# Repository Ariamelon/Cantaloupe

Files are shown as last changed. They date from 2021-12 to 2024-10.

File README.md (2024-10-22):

# Cantaloupe
~60% QMK-compatible split ergonomic keyboard.

## Disclaimer
This keyboard is licensed under CERN-OHL-S-2.0. The layout is based on the [Ergodash](https://github.com/omkbd/ErgoDash) layout with the inner-most keys removed and an improved thumb cluster. The layout was only used as a reference, nothing was copied and the board is a completely new design. In addition, design cues from the [YAEMK](https://karlk90.github.io/yaemk-split-kb/) were used in this design.

## Key Features
* Ergonomic 30-key layout including pinky stagger and arrow keys.
* MX switches with kailh hot-swap sockets.
* 100% reversible design which means only a single board is needed for both sides.
* 0.96" 128x64 SSD1306 OLED support.
* Two rotary encoders supported above the thumb cluster, one on each side.
* Support for the Pimoroni trackball module is also available, replacing one rotary encoder slot.
* On-board ARM STM32F401CCU6 processor.
* USB-C input and split connect ports with full ESD protection.
* SWD breakout header for an alternate means of programming the board.

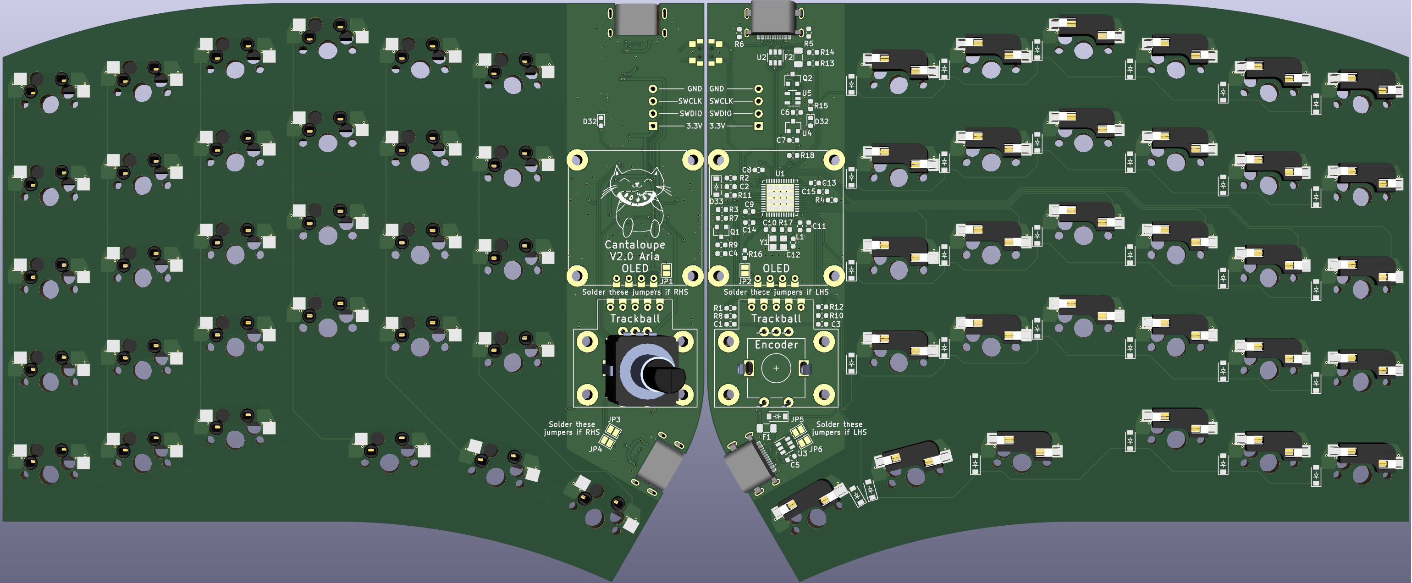
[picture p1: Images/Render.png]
Cantaloupe Front Render

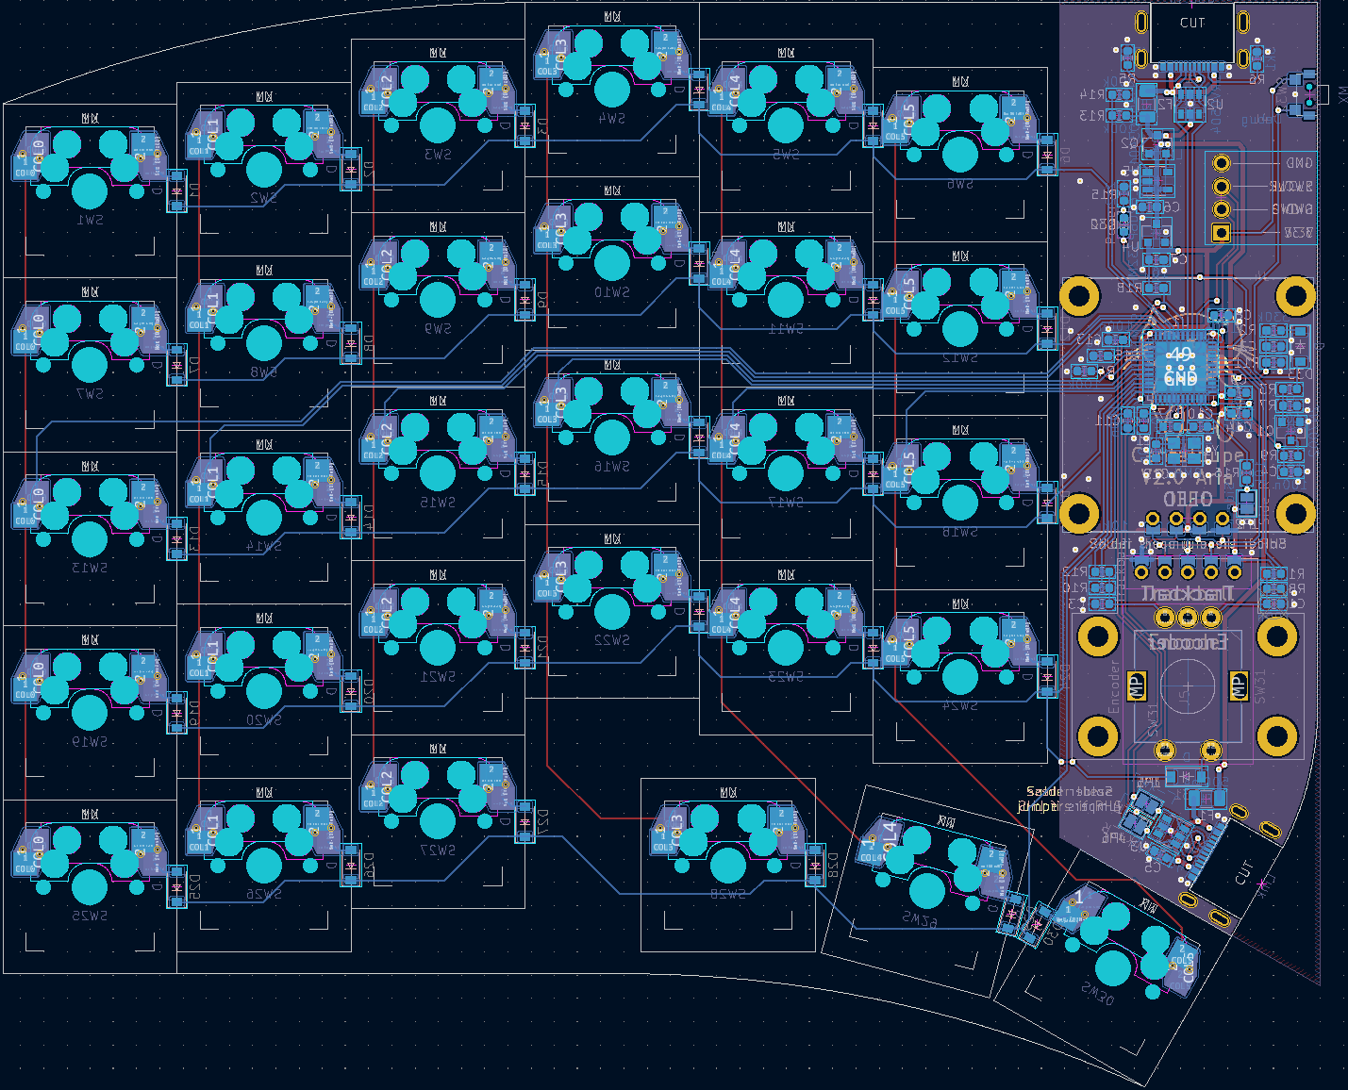
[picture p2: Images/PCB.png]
Cantaloupe PCB

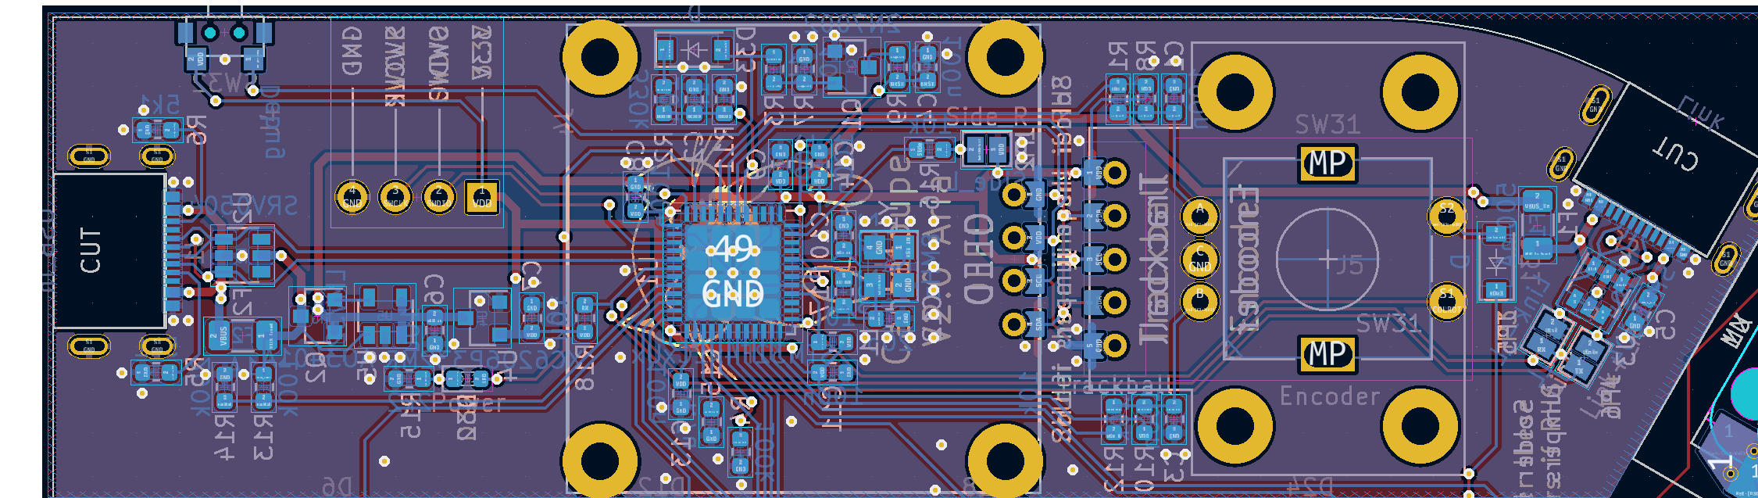
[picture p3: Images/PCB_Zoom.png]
Cantaloupe PCB Zoomed

Cantaloupe Schematic

## Changelog
* 22/10/2024: License updated to CERN-OHL-S-2.0.
* 14/5/2022: Added silkscreen jumper guides. Connected indicator LED to spare GPIO. Updated images.
* 13/5/2022: Finalized firmware. Added custom graphic to OLED display. Updated 3DP case and BOM. Removed CNC case. Fixed error with silkscreen. Added silkscreen jumper guides.
* 15/2/2022: Revised 3DP and CNC case designs.
* 13/2/2022: Added tentative designs for CNC and 3D printed cases. 
* 11/2/2022: Clean up of design. New images. Added gerbers and files for FR4 plates.
* 9/2/2022: Changed pin assignments so B2 isn't used. Added pull-up for RX pin and pull-down for B2 pin so the keyboard can properly load into the bootloader. Changed reset circuit so it actually works. Removed USB series resistors. Removed non-functional JTAG pins. Changed SRV05-04 to SRV0504. Thanks to sigprof and MasterSpoon from the QMK discord server for the help!
* 8/2/2022: Removed holes in middle of PCB. Added top and bottom plate DXF files, as well as a tentative STEP file for a CNC case. 
* 25/1/2022: Did some rerouting, increased clearances and via size.
* 21/1/2022: Changed CPU to STM32F4x1CxUx (lets me steal them from Black Pill boards). Added plate and base gerber files. Changed BOM to reflect changes.
* 20/1/2022: Cleaned up read-me. Rearranged location of mounting holes and changed size of holes. Rerouted some traces. Cleaned up silkscreen. Added DXF files for plate and base. Changed images. Added BOM.
* 19/1/2022: New V2.0 version. On-board ARM STM32F303 processor, kailh hot-swap, ESD protection, 0.96" OLED, trackball and rotary encoder. 100% reversible design which means only a single board is needed for both sides. Plenty of design cues taken from the YAEMK. Pinky stagger added.

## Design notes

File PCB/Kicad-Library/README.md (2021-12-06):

# Kicad Library
 Aria's library of footprints

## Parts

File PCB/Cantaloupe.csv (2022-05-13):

PCB | For one half
Qty | Reference(s) | Value | Description | LCSC Part number
8 | C1, C3, C4, C8, C9, C11, C13, C14 | 100n | 0603 capacitor | C14663
4 | C2, C5, C6, C7 | 10u | 0603 capacitor | C19702
2 | C10, C12 | 20p | 0603 capacitor | C1648
1 | C15 | 4.7u | 0603 capacitor | C1705
32 | D1 - D31, D33 | 1N4148 | SOD123 diode | C81598
1 | D32 | Any colour LED | 0603 LED | C264479
1 | F1 | 0.5A | 1206 fuse | C69688
1 | F2 | 1A | 1206 fuse | C66453
2 | J1,J3 | - | USB C mid-mount port | C168688
1 | J2 | OLED socket | 4-pin female vertical header | C2889986
1 | J4 | Debug socket | 6-pin male right angled header | C56816
1 | J5 | Trackball socket | 5-pin female vertical header | C2889987
1 | L1 | 10u | 0603 inductor | C92982
1 | Q1 | 2N7002 | SOT-23 transistor | C8545
1 | Q2 | AO3401A | SOT-23 transistor | C15127
7 | R1, R7, R8, R10, R12, R16, R18 | 10k | 0603 resistor | C25804
1 | R2 | 330k | 0603 resistor | C23137
1 | R3 | 1k | 0603 resistor | C21190
2 | R4, R13 | 100k | 0603 resistor | C25803
2 | R5, R6 | 5k1 | 0603 resistor | C23186
1 | R9 | 100 | 0603 resistor | C22775
1 | R11 | 1M | 0603 resistor | C22935
1 | R14 | 200k | 0603 resistor | C25811
1 | R15 | 2k2 | 0603 resistor | C4190
1 | R17 | 220 | 0603 resistor | C22962
30 | SW1-SW30 | - | Kailh hotswap socket
1 | SW31 | EC11 | Max 30mm knob | C470748
1 | SW32 | - | Momentary pushbutton | C393942
1 | U1 | STM32F4x1CxUx | QFN-44 MCU | C79861
2 | U2, U3 | SRV0504 | SOT-26 ESD protector | C384888
1 | U4 | XC6206P332MR | SOT-25 3.3v LDO | C5446
1 | U5 | LMV321 | SOT-25 opamp | C90297
1 | Y1 | 8MHz | 3225 crystal | C403948
Case
Qty | Value | Description
1 |  | Top plate
1 |  | Bottom plate
12 | M2x8mm | Threaded standoff
24 | M2x4mm | Panhead screw
OLED
Qty | Value | Description
1 | SSD1306 0.96" | OLED display
4 | M2x5mm | Threaded standoff
4 | M2x4mm | Panhead screw
Trackball
Qty | Value | Description
1 | - | Pimoroni trackball
4 | M2x11mm | Threaded standoff
4 | M2x4mm | Panhead screw

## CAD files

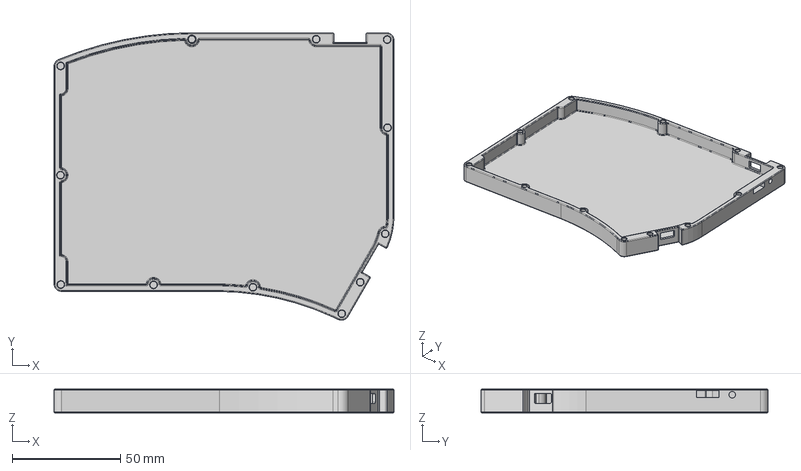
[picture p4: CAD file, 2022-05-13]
Case/3DP/Case_3DP_L.step
156.9 x 132.7 x 11.0 mm

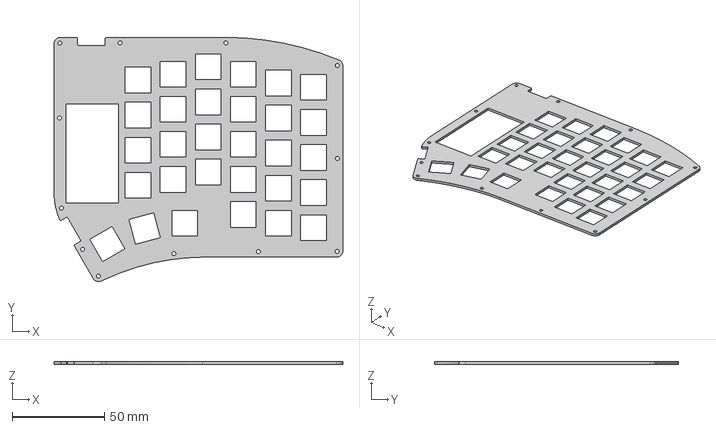
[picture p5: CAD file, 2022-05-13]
Case/Plate/Case_Plate.step
156.9 x 132.7 x 1.50 mm

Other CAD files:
Case/3DP/Case_3DP_R.step

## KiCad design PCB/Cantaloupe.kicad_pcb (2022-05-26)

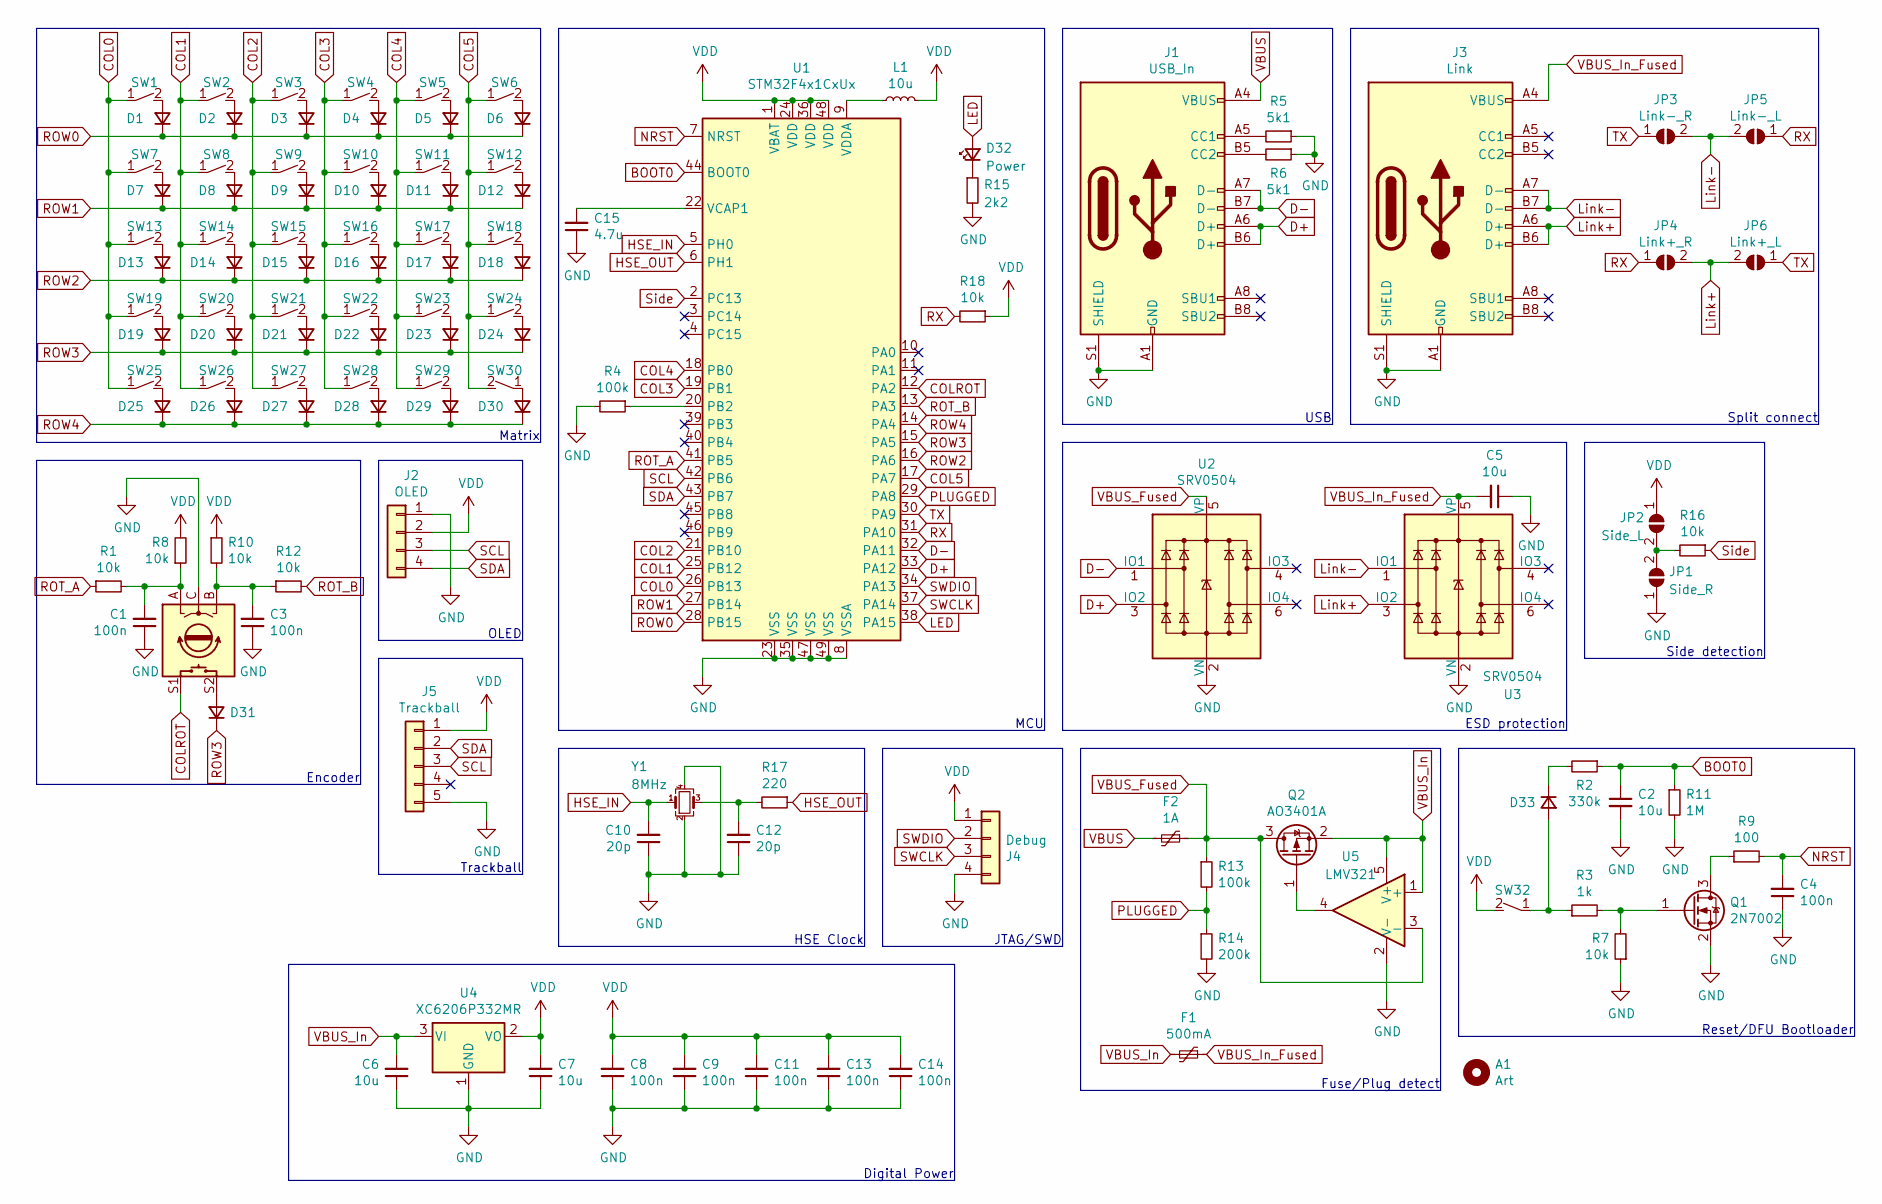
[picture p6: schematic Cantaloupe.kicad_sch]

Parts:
A1: Art; Catmelon
C1, C3, C4, C8, C9, C11, C13, C14: 100n; C_0603_1608Metric
C2, C5, C6, C7: 10u; C_0603_1608Metric
C10, C12: 20p; C_0603_1608Metric
C15: 4.7u; C_0603_1608Metric
D1, D2, D3, D4, D5, D6, D7, D8, D9, D10, D11, D12, D13, D14, D15, D16, D17, D18, D19, D20, D21, D22, D23, D24, D25, D26, D27, D28, D29, D30, D31, D33: D; D_SOD-123
D32: Power; LED_0603_1608Metric_Flippable
F1: 500mA; Fuse_1206_3216Metric
F2: 1A; Fuse_1206_3216Metric
J1: USB_In; USB-C-C168688
J2: OLED; OLED_0.96_SSD1306_128x64_Flippable
J3: Link; USB-C-C168688
J4: Debug; Debug_JTAG_SWD
J5: Trackball; pimoroni_trackball_flippable
JP1: Side_R; SolderJumper-2_P1.3mm_Open_Pad1.0x1.5mm
JP2: Side_L; SolderJumper-2_P1.3mm_Open_Pad1.0x1.5mm
JP3: Link-_R; SolderJumper-2_P1.3mm_Open_Pad1.0x1.5mm
JP4: Link+_R; SolderJumper-2_P1.3mm_Open_Pad1.0x1.5mm
JP5: Link-_L; SolderJumper-2_P1.3mm_Open_Pad1.0x1.5mm
JP6: Link+_L; SolderJumper-2_P1.3mm_Open_Pad1.0x1.5mm
L1: 10u; L_0603_1608Metric
Q1: 2N7002; SOT-23
Q2: AO3401A; SOT-23
R1, R7, R8, R10, R12, R16, R18: 10k; R_0603_1608Metric
R2: 330k; R_0603_1608Metric
R3: 1k; R_0603_1608Metric
R4, R13: 100k; R_0603_1608Metric
R5, R6: 5k1; R_0603_1608Metric
R9: 100; R_0603_1608Metric
R11: 1M; R_0603_1608Metric
R14: 200k; R_0603_1608Metric
R15: 2k2; R_0603_1608Metric
R17: 220; R_0603_1608Metric
SW1, SW2, SW3, SW4, SW5, SW6, SW7, SW8, SW9, SW10, SW11, SW12, SW13, SW14, SW15, SW16, SW17, SW18, SW19, SW20, SW21, SW22, SW23, SW24, SW25, SW26, SW27, SW28, SW29, SW30: MX; MXOnly-1U-Hotswap-Dual
SW31: Encoder; EC11_Flippable
SW32: MX; Switch_TS24CA_Flippable
U1: STM32F4x1CxUx; QFN-48-1EP_7x7mm_P0.5mm_EP5.6x5.6mm
U2, U3: SRV0504; SOT-23-6
U4: XC6206P332MR; SOT-23
U5: LMV321; SOT-23-5
Y1: 8MHz; Crystal_SMD_3225-4Pin_3.2x2.5mm

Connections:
BOOT0: C2.1, R2.1, R11.1, U1.44 (BOOT0)
COL0: SW1.1 (A), SW7.1 (A), SW13.1 (A), SW19.1 (A), SW25.1 (A), U1.26 (PB13)
COL1: SW2.1 (A), SW8.1 (A), SW14.1 (A), SW20.1 (A), SW26.1 (A), U1.25 (PB12)
COL2: SW3.1 (A), SW9.1 (A), SW15.1 (A), SW21.1 (A), SW27.1 (A), U1.21 (PB10)
COL3: SW4.1 (A), SW10.1 (A), SW16.1 (A), SW22.1 (A), SW28.1 (A), U1.19 (PB1)
COL4: SW5.1 (A), SW11.1 (A), SW17.1 (A), SW23.1 (A), SW29.1 (A), U1.18 (PB0)
COL5: SW6.1 (A), SW12.1 (A), SW18.1 (A), SW24.1 (A), SW30.2 (B), U1.17 (PA7)
COLROT: SW31.S1, U1.12 (PA2)
D+: J1.A6 (D+), J1.B6 (D+), U1.33 (PA12), U2.3 (IO2)
D-: J1.A7 (D-), J1.B7 (D-), U1.32 (PA11), U2.1 (IO1)
GND: C1.1, C2.2, C3.1, C4.1, C5.1, C6.1, C7.1, C8.1, C9.1, C10.1, C11.1, C12.1, C13.1, C14.1, C15.1, J1.A1 (GND), J1.A12 (GND), J1.B1 (GND), J1.B12 (GND), J1.S1 (SHIELD), J2.1, J3.A1 (GND), J3.A12 (GND), J3.B1 (GND), J3.B12 (GND), J3.S1 (SHIELD), J4.4, J5.5, JP1.1 (A), Q1.2 (S), R4.2, R5.1, R6.1, R7.1, R11.2, R14.2, R15.2, SW31.C, U1.8 (VSSA), U1.23 (VSS), U1.35 (VSS), U1.47 (VSS), U1.49 (VSS), U2.2 (VN), U3.2 (VN), U4.1 (GND), U5.2 (V-), Y1.2, Y1.4
HSE_IN: C10.2, U1.5 (PH0), Y1.1
HSE_OUT: R17.1, U1.6 (PH1)
LED: D32.2 (A), U1.38 (PA15)
Link+: J3.A6 (D+), J3.B6 (D+), JP4.2 (B), JP6.2 (B), U3.3 (IO2)
Link-: J3.A7 (D-), J3.B7 (D-), JP3.2 (B), JP5.2 (B), U3.1 (IO1)
NRST: C4.2, R9.2, U1.7 (NRST)
unnamed: C1.2, R1.2, R8.1, SW31.A
unnamed: C3.2, R10.2, R12.1, SW31.B
unnamed: C12.2, R17.2, Y1.3
unnamed: C15.2, U1.22 (VCAP1)
unnamed: D1.2 (A), SW1.2 (B)
unnamed: D2.2 (A), SW2.2 (B)
unnamed: D3.2 (A), SW3.2 (B)
unnamed: D4.2 (A), SW4.2 (B)
unnamed: D5.2 (A), SW5.2 (B)
unnamed: D6.2 (A), SW6.2 (B)
unnamed: D7.2 (A), SW7.2 (B)
unnamed: D8.2 (A), SW8.2 (B)
unnamed: D9.2 (A), SW9.2 (B)
unnamed: D10.2 (A), SW10.2 (B)
unnamed: D11.2 (A), SW11.2 (B)
unnamed: D12.2 (A), SW12.2 (B)
unnamed: D13.2 (A), SW13.2 (B)
unnamed: D14.2 (A), SW14.2 (B)
unnamed: D15.2 (A), SW15.2 (B)
unnamed: D16.2 (A), SW16.2 (B)
unnamed: D17.2 (A), SW17.2 (B)
unnamed: D18.2 (A), SW18.2 (B)
unnamed: D19.2 (A), SW19.2 (B)
unnamed: D20.2 (A), SW20.2 (B)
unnamed: D21.2 (A), SW21.2 (B)
unnamed: D22.2 (A), SW22.2 (B)
unnamed: D23.2 (A), SW23.2 (B)
unnamed: D24.2 (A), SW24.2 (B)
unnamed: D25.2 (A), SW25.2 (B)
unnamed: D26.2 (A), SW26.2 (B)
unnamed: D27.2 (A), SW27.2 (B)
unnamed: D28.2 (A), SW28.2 (B)
unnamed: D29.2 (A), SW29.2 (B)
unnamed: D30.2 (A), SW30.1 (A)
unnamed: D31.2 (A), SW31.S2
unnamed: D33.1 (K), R2.2
unnamed: D33.2 (A), R3.1, SW32.1 (A)
unnamed: J1.A5 (CC1), R5.2
unnamed: J1.B5 (CC2), R6.2
unnamed: JP1.2 (B), JP2.2 (B), R16.2
unnamed: L1.1, U1.9 (VDDA)
unnamed: Q1.1 (G), R3.2, R7.2
unnamed: Q1.3 (D), R9.1
unnamed: Q2.1 (G), U5.4
unnamed: R4.1, U1.20 (PB2)
unnamed: D32.1 (K), R15.1
PLUGGED: R13.2, R14.1, U1.29 (PA8)
ROT_A: R1.1, U1.41 (PB5)
ROT_B: R12.2, U1.13 (PA3)
ROW0: D1.1 (K), D2.1 (K), D3.1 (K), D4.1 (K), D5.1 (K), D6.1 (K), U1.28 (PB15)
ROW1: D7.1 (K), D8.1 (K), D9.1 (K), D10.1 (K), D11.1 (K), D12.1 (K), U1.27 (PB14)
ROW2: D13.1 (K), D14.1 (K), D15.1 (K), D16.1 (K), D17.1 (K), D18.1 (K), U1.16 (PA6)
ROW3: D19.1 (K), D20.1 (K), D21.1 (K), D22.1 (K), D23.1 (K), D24.1 (K), D31.1 (K), U1.15 (PA5)
ROW4: D25.1 (K), D26.1 (K), D27.1 (K), D28.1 (K), D29.1 (K), D30.1 (K), U1.14 (PA4)
RX: JP4.1 (A), JP5.1 (A), R18.2, U1.31 (PA10)
SCL: J2.3, J5.3, U1.42 (PB6)
SDA: J2.4, J5.2, U1.43 (PB7)
SWCLK: J4.3, U1.37 (PA14)
SWDIO: J4.2, U1.34 (PA13)
Side: R16.1, U1.2 (PC13)
TX: JP3.1 (A), JP6.1 (A), U1.30 (PA9)
VBUS: F2.2, J1.A4 (VBUS), J1.A9 (VBUS), J1.B4 (VBUS), J1.B9 (VBUS)
VBUS_Fused: F2.1, Q2.3 (D), R13.1, U2.5 (VP), U5.3 (-)
VBUS_In: C6.2, F1.2, Q2.2 (S), U4.3 (VI), U5.1 (+), U5.5 (V+)
VBUS_In_Fused: C5.2, F1.1, J3.A4 (VBUS), J3.A9 (VBUS), J3.B4 (VBUS), J3.B9 (VBUS), U3.5 (VP)
VDD: C7.2, C8.2, C9.2, C11.2, C13.2, C14.2, J2.2, J4.1, J5.1, JP2.1 (A), L1.2, R8.2, R10.1, R18.1, SW32.2 (B), U1.1 (VBAT), U1.24 (VDD), U1.36 (VDD), U1.48 (VDD), U4.2 (VO)

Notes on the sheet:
HSE Clock
USB
Encoder
Matrix
Side detection
JTAG/SWD
Digital Power
Fuse/Plug detect
ESD protection
OLED
MCU
Reset/DFU Bootloader
Split connect
Trackball

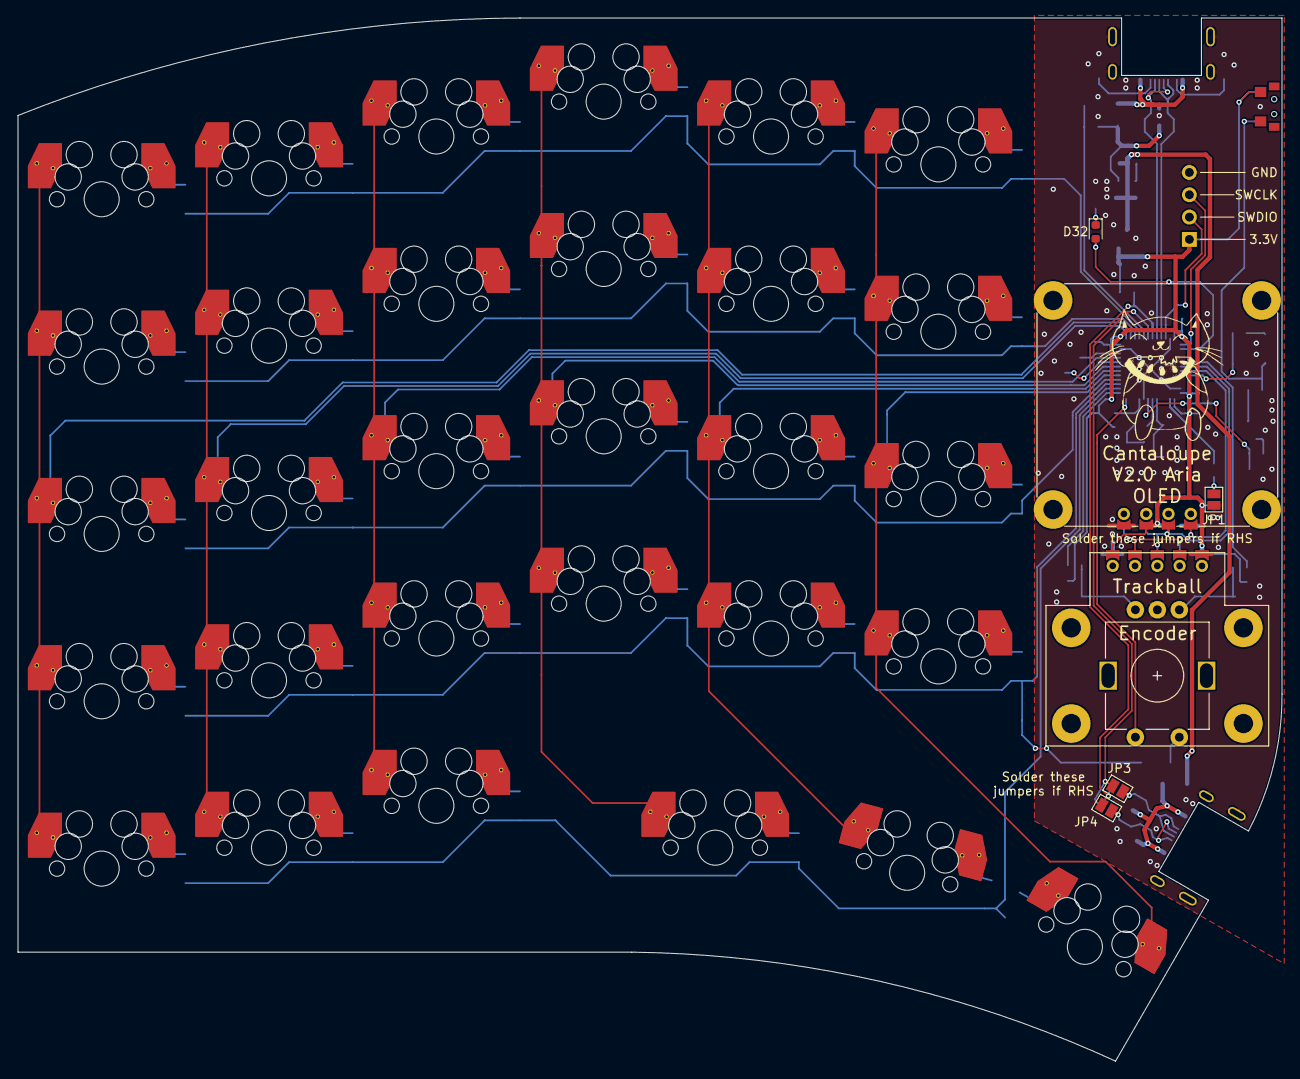
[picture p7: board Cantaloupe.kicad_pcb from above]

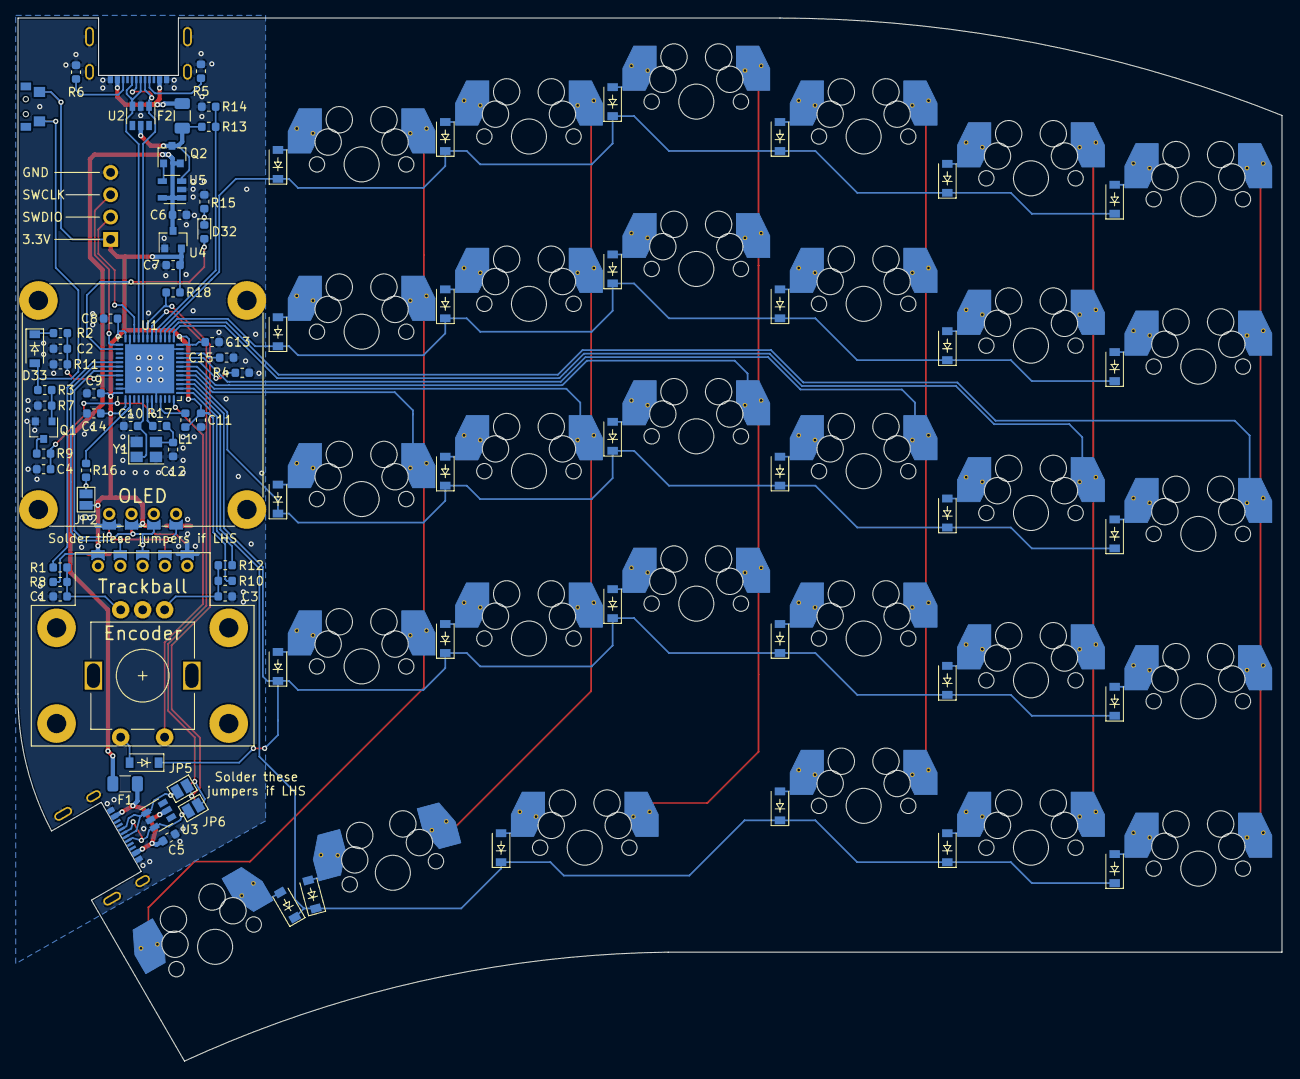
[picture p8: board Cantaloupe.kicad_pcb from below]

Board: 2 copper layers, 143.9 x 118.7 mm, 121 parts (83 on the bottom side), 83 nets.

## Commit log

2020-09-27 Cantaloupe V1
    Added.
    [Cant_Plate_V3.dxf, Cantaloupe-B_Adhes.dxf, Cantaloupe-B_CrtYd.dxf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]
2020-09-27 Renamed folder
    [Cant_Plate_V3.dxf, Cantaloupe-B_Adhes.dxf, Cantaloupe-B_CrtYd.dxf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]
2020-09-28 Proper case files and gerbers
    Added an STL file for a rudimentary 3D-printed case for the Cantaloupe as well as DXF and Gerber files for a plate.
    [Cantaloupe-B_Adhes.dxf, Cantaloupe-B_CrtYd.dxf, Cantaloupe-B_Cu.dxf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]
2020-09-28 Added BOM
    [Cantaloupe-BOM.csv, Cantaloupe-BOM.xlsx, Cantaloupe.sch]
2020-09-28 Interconnect changed to C-168688
    Changed interconnect footprint to USB C-168688 due to lack of widespread availability of previous part.
    [Cantaloupe-B_Cu.gbr, Cantaloupe-B_Mask.gbr, Cantaloupe-B_Paste.gbr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]
2020-09-30 Fixed silk
    [Cantaloupe.kicad_pcb]
2020-10-24 Updated to V1.1
    [Cantaloupe-B_Cu.gbr, Cantaloupe-B_Mask.gbr, Cantaloupe-B_Paste.gbr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]
2020-10-24 Increased gap between halves
    [Cantaloupe.kicad_pcb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]
2020-10-27 Better photo, reorganized footprints, minor fixes to circuit
    [Cantaloupe.kicad_pcb, Cantaloupe.sch]
2020-10-29 Minor fix to position of RHS OLED
    [Cantaloupe.kicad_pcb]
2020-10-31 Fixed minor silk error
    [Cantaloupe.kicad_pcb]
2020-11-06 Fixed position of RHS screw hole and wiring of rotary encoder switch, added QMK firmware.
    [Cantaloupe.kicad_pcb, Cantaloupe.sch]
2020-11-10 Updated to V1.2
    [Cantaloupe.kicad_pcb, Cantaloupe.sch, Cantaloupe_Plate.kicad_pcb]
2020-11-13 Changed USB C connector to normal from mid-mount
    [Cantaloupe.kicad_pcb, Cantaloupe.sch, Cantaloupe_Plate.kicad_pcb]
2020-11-14 Added alps-compatible fr4 plate and cnc alu case STEP files
    [Cantaloupe.kicad_pcb, Cantaloupe_Plate_MXAlps.kicad_pcb, Case_L.step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]
2020-11-28 Updated to V1.3.
    [Cantaloupe.kicad_pcb, Cantaloupe.sch, Cantaloupe_Base.kicad_pcb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]
2020-11-29 Updated position of diode
    [Cantaloupe.kicad_pcb]
2020-11-30 Changed OLED support to 0.96" OLED
    [Cantaloupe.kicad_pcb, Cantaloupe.sch, Cantaloupe_Base.kicad_pcb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]
2020-12-02 Changed orientation of 1u switches in thumb cluster. Updated plate to add 2u support.
    [Cantaloupe.kicad_pcb, Cantaloupe.sch, Cantaloupe_Plate.kicad_pcb]
2021-05-08 Updated BOM
    [Cantaloupe-BOM.csv, Cantaloupe-BOM.xlsx]
2021-05-16 Added proper OLED support.
    [Cantaloupe.kicad_pcb, Cantaloupe_Plate.kicad_pcb]
2021-07-20 Updated to V1.4.
    [Cantaloupe.kicad_pcb, Cantaloupe.sch, Cantaloupe_Base.kicad_pcb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]
2021-07-20 Fixed PCB image
2021-10-01 Added SMK support
    [Cantaloupe.kicad_pcb, Cantaloupe.sch, Cantaloupe_Plate.kicad_pcb]
2021-12-06 Updated to V1.5.
    Added the option for OLED again. Removed Alps support. Improved switch footprints. Removed 2u support and moved rotary encoder positions. Deleted 61st and 62nd keyswitches - now has exactly 30 switch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
    [Cantaloupe.kicad_pcb, Cantaloupe.sch, Cantaloupe_Base.dxf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]
2022-01-19 New ARM variant (experimental WIP)
    [Cantaloupe-BOM.csv, Cantaloupe.kicad_pcb, Cantaloupe.sch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]
2022-01-20 20/1/2022 update
    Cleaned up read-me. Rearranged location of mounting holes and changed size of holes. Rerouted some traces. Cleaned up silkscreen. Added DXF files for plate and base. Changed images. Added BOM.
    [Base.dxf, Cantaloupe.csv, Cantaloupe.kicad_pcb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]
2022-01-21 STM32F4x0 version
    [Cantaloupe.csv, Cantaloupe.kicad_pcb, Cantaloupe.sch]
2022-01-21 Added case gerbers
    [Base.kicad_pcb, Cantaloupe.csv, Plate.kicad_pcb]
2022-01-25 Did some rerouting, increased clearances and via size, updated footprint master
    [Cantaloupe.kicad_pcb, Cantaloupe.sch]
2022-01-25 Added V1.6
    V1.6 is the same as V2.0 but with a pro micro slot instead of the on-board ARM MCU. Separated V1.6 and V2.0 into specific folders. Added version-specific readme and images.
    [Base.kicad_pcb, Cantaloupe.csv, Cantaloupe.kicad_pcb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]
2022-02-08 New plate files, removed internal holes from PCB
    [Base.dxf, Base.kicad_pcb, Cantaloupe.kicad_pcb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]
2022-02-08 Fixed plate DXF files, added tentative .STEP file for a CNC case
    [Base.dxf, Cantaloupe.kicad_pcb, Case.step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]
2022-02-09 Fixed issues with PCB
    Changed pin assignments so B2 isn't used. Added pull-up for RX pin and pull-down for B2 pin so it can properly load into the bootloader.
    [Cantaloupe.kicad_pcb, Cantaloupe.sch]
2022-02-10 Fixed many issues with the board
    Changed pin assignments so B2 isn't used. Added pull-up for RX pin and pull-down for B2 pin so the keyboard can properly load into the bootloader. Changed reset circuit so it actually works. Removed USB series resistors. Removed non-functional JTAG pins. Changed SRV05-04 to SRV0504. Thanks to sigprof and MasterSpoon from the QMK discord server for the help!
    [Cantaloupe.csv, Cantaloupe.kicad_pcb, Cantaloupe.sch]
2022-02-10 Removed PCB mounting holes. Slightly changed position of reset switch.
    [Cantaloupe.kicad_pcb, Cantaloupe.sch]
2022-02-10 Rearranged schematic
    [Cantaloupe.sch]
2022-02-11 Clean up of design. Added gerbers and files for FR4 plates.
    [Base.kicad_pcb, Cantaloupe.kicad_pcb, Cantaloupe.sch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]
2022-02-11 Fixed jumper side
    [Cantaloupe.kicad_pcb, Cantaloupe.sch]
2022-02-13 Added tentative designs for CNC and 3D printed cases
    [Base.dxf, Base.kicad_pcb, Case.step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]
2022-02-15 Revised 3DP and CNC case designs
    [Case.step, Case_3DP_L.step, Case_3DP_L.stl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]
2022-02-18 Added 3D files for top plate
    [Plate_Top.step, Plate_Top.stl]
2022-05-13 Finalized firmware. Added custom graphic to OLED display. Updated 3DP case and BOM. Fixed error with silkscreen.
    [Base.dxf, Base.kicad_pcb, Cantaloupe.csv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]
2022-05-26 Updates
    Update README.md. Added silkscreen jumper guides. Connected indicator LED to spare GPIO. Updated images.
    [Cantaloupe.csv, Cantaloupe.kicad_pcb, Cantaloupe.kicad_sch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]
